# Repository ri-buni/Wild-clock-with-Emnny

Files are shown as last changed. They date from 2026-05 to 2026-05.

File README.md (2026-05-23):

# Wild-clock-with-Emnny
Emnny is a small AI powered mascot. When I say the wake word, he wakes up, listens to me and answers in his own voice. The rest of the time, he just shows current time and quietly exists!

# PCB
Made in KiCad

Schematic

anydesk00002

PCB

anydesk00000

# Case
Made in Fusion360

anydesk00004
anydesk00001
anydesk00003

# Firmware
Was written by Claude Code

# BOM

- [INMP441](https://aliexpress.ru/item/1005004862555297.html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)
- [Speakers](https://aliexpress.ru/item/1005007315336158.html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)
- [Amplifier chip](https://aliexpress.ru/item/1005006942750928.html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)
- [ESP32 S3 WROOM 1](https://aliexpress.ru/item/1005005567013022.html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)
- [Buttons](https://aliexpress.ru/item/1005007623070623.html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)
- [LiPo 3.7V 2000mah](https://aliexpress.ru/item/1005008217717191.html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)
- [TP4056 chip](https://aliexpress.ru/item/32714366180.html?spm=a2g2w.cart.cart_split.9.77b34aa6A5IoAS&sku_id=61056856324)
- [LDO](https://aliexpress.ru/item/1005004159688937.html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)
- [Display](https://aliexpress.ru/item/1005008770450001.html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)
- [USBLC6 2SC6](https://aliexpress.ru/item/1005009468432448.html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)
- [USB Type C connector](https://aliexpress.ru/item/1005007694777041.html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)
Total ~35$

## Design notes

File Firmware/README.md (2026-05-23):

# README AND WHOLE CODE WAS MADE BY CLAUDE CODE

# Bunbun — ESP32-S3 AI Clock

Tiny AI bunny that lives in your clock. Talks to you, sasses you, sleeps when
you tell it to from your phone.

## Hardware

| Part | Notes |
|---|---|
| ESP32-S3-WROOM-1 | dev board with USB (Devkit-C-1 or similar). PSRAM required. |
| 2.42" OLED 128×64 | SSD1309 (or SH1106) over I²C |
| INMP441 | I²S MEMS microphone |
| MAX98357A | I²S DAC + class-D amp |
| Speaker | 4Ω or 8Ω small speaker, ~1W |

## Wiring (matches `config.h`)

```
OLED:        VCC→3V3, GND→GND, SDA→GPIO8,  SCL→GPIO9
INMP441:     VDD→3V3, GND→GND, L/R→GND, SCK→GPIO4, WS→GPIO5, SD→GPIO6
MAX98357A:   VIN→5V,  GND→GND, BCLK→GPIO15, LRC→GPIO16, DIN→GPIO7
             GAIN: leave floating for ~9dB, tie to GND for max
             SD: tie to VIN (or to a GPIO if you want to mute via code)
Speaker:     to MAX98357A speaker pads
```

The INMP441's L/R pin determines which I²S slot the mic uses. Tie it to GND
(left). If you tie it to VDD instead, change `I2S_CHANNEL_FMT_ONLY_LEFT` to
`I2S_CHANNEL_FMT_ONLY_RIGHT` in `audio.cpp`.

## First-time setup

1. **Install PlatformIO** in VS Code (search for "PlatformIO IDE" in the
   extensions panel). Arduino IDE will *not* work for this project because
   Porcupine's static library needs PlatformIO's build system.

2. **Get free API keys:**
   - **Groq** — go to <https://console.groq.com>, sign up, copy your key
     (free tier: 2000 Whisper requests/day, plenty of Llama and TTS)
   - **Picovoice** — go to <https://console.picovoice.ai>, sign up, copy your
     AccessKey (free for personal use)

3. **Train your "Hey Bunny" wake word** at the Picovoice Console:
   - Console → Porcupine → "Create Wake Word"
   - phrase: "Hey Bunny"
   - platform: **ESP32-S3**
   - download the `.ppn` file
   - convert it to a C header: `xxd -i hey_bunny_esp32.ppn > hey_bunny_ppn.h`
   - drop `hey_bunny_ppn.h` into `lib/porcupine/`

4. **Get the Porcupine ESP32-S3 SDK** from the Picovoice GitHub
   (<https://github.com/Picovoice/porcupine>), place the static library
   (`libpv_porcupine.a`) and headers (`pv_porcupine.h`, etc.) into
   `lib/porcupine/`.

5. **Edit `include/config.h`:**
   - `WIFI_SSID`, `WIFI_PASSWORD` — your network (or phone hotspot)
   - `GROQ_API_KEY` — from step 2
   - `PICOVOICE_ACCESS_KEY` — from step 2
   - `BUNNY_PERSONALITY` — write the bunny's voice in a few sentences
   - `TZ_OFFSET_SEC` — your timezone (default is UTC+5 / Almaty)

6. **Flip `USE_PORCUPINE` to 1** in `src/wake_word.cpp` once steps 3 and 4
   are done. Until then the project runs with a fallback: shout or clap loudly
   to "wake" it (good for testing everything else).

7. **Build and upload:** in PlatformIO sidebar, click the checkmark to build,
   then the arrow to upload. Open the serial monitor at 115200 baud.

## Using it

- Once it boots, it'll print the IP address. Open `http://<that-ip>/` on your
  phone (same WiFi). You'll see a pink toggle. Tap to turn AI on/off.
- Say "hey bunny" (or shout in fallback mode), then ask your question.
- It'll record until you stop talking (or ~7s max), transcribe via Whisper,
  reply via Llama with your personality prompt, and speak it via PlayAI.
- The OLED shows time and the bunny throughout. Clock stays on always.

## Tuning

- **mic too quiet** → in `audio.cpp`, decrease the `raw[i] >> 14` shift to
  `>> 12` (louder) or `>> 16` (quieter)
- **records too long / never stops** → lower `2000` energy threshold in
  `audio_record_to_wav`
- **replies too long for tiny speaker** → lower `max_tokens` in `groq.cpp`
  or tighten `BUNNY_PERSONALITY`'s "keep replies SHORT" line
- **voice not expressive enough** → try `Cheyenne-PlayAI`, `Indigo-PlayAI`,
  `Quinn-PlayAI`. tell the personality prompt to use `[whisper]`, `[cheerful]`,
  `[sigh]` tags

## Files

```
bunny_clock/
├── platformio.ini       PlatformIO config
├── include/
│   ├── config.h         all editable settings ← look here first
│   └── bitmaps.h        bunny pixel data (will update once you re-send images)
├── lib/porcupine/       (you create — see step 4 above)
└── src/
    ├── main.cpp         setup/loop + state machine
    ├── display.h/.cpp   OLED
    ├── audio.h/.cpp     I²S mic + speaker
    ├── wake_word.h/.cpp Porcupine + energy fallback
    ├── groq.h/.cpp      STT + LLM + TTS
    └── webserver.h/.cpp phone toggle page
```

## Known limitations / things you may need to fix on real hardware

- HTTPS to Groq uses `setInsecure()`. Fine for personal use; for proper
  security pin the Groq root CA in `groq.cpp`.
- The fallback wake-word detector (energy spike) will false-trigger on any
  loud sound. Install Porcupine for the real wake word.
- Recording uses a fixed 16kHz buffer in PSRAM. If your board lacks PSRAM,
  reduce `MAX_RECORD_SECONDS` and the buffer will go in regular RAM.
- The OLED constructor in `display.cpp` is `SSD1309`. If yours is `SH1106`,
  swap the commented-out line.
- INMP441 needs ~1 second after power-up to be stable. If the very first
  recording is garbage, add `delay(1000)` after `audio_begin()`.

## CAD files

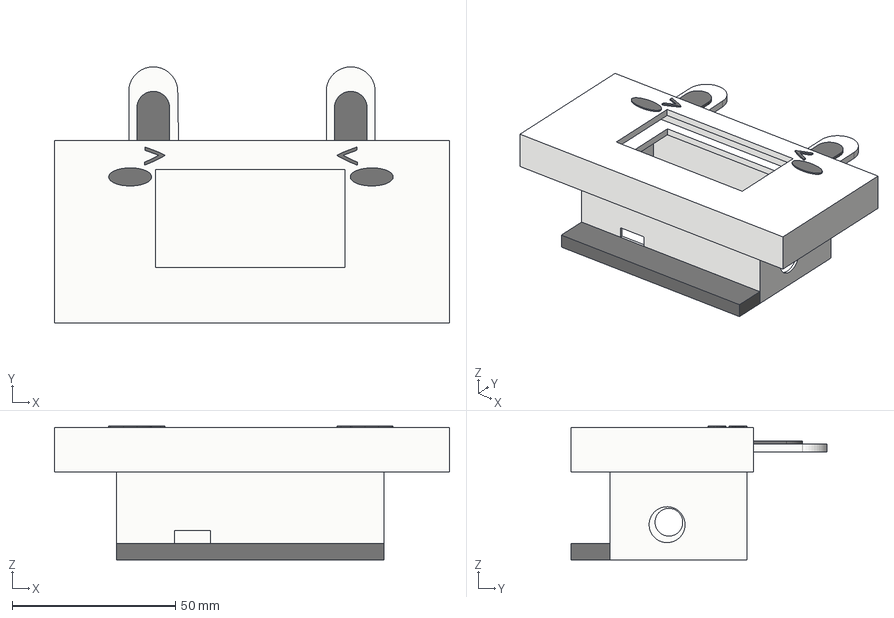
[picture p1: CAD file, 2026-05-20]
Production/wild clock case.step
121.0 x 78.5 x 41.0 mm

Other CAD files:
CAD/wild clock case.f3z

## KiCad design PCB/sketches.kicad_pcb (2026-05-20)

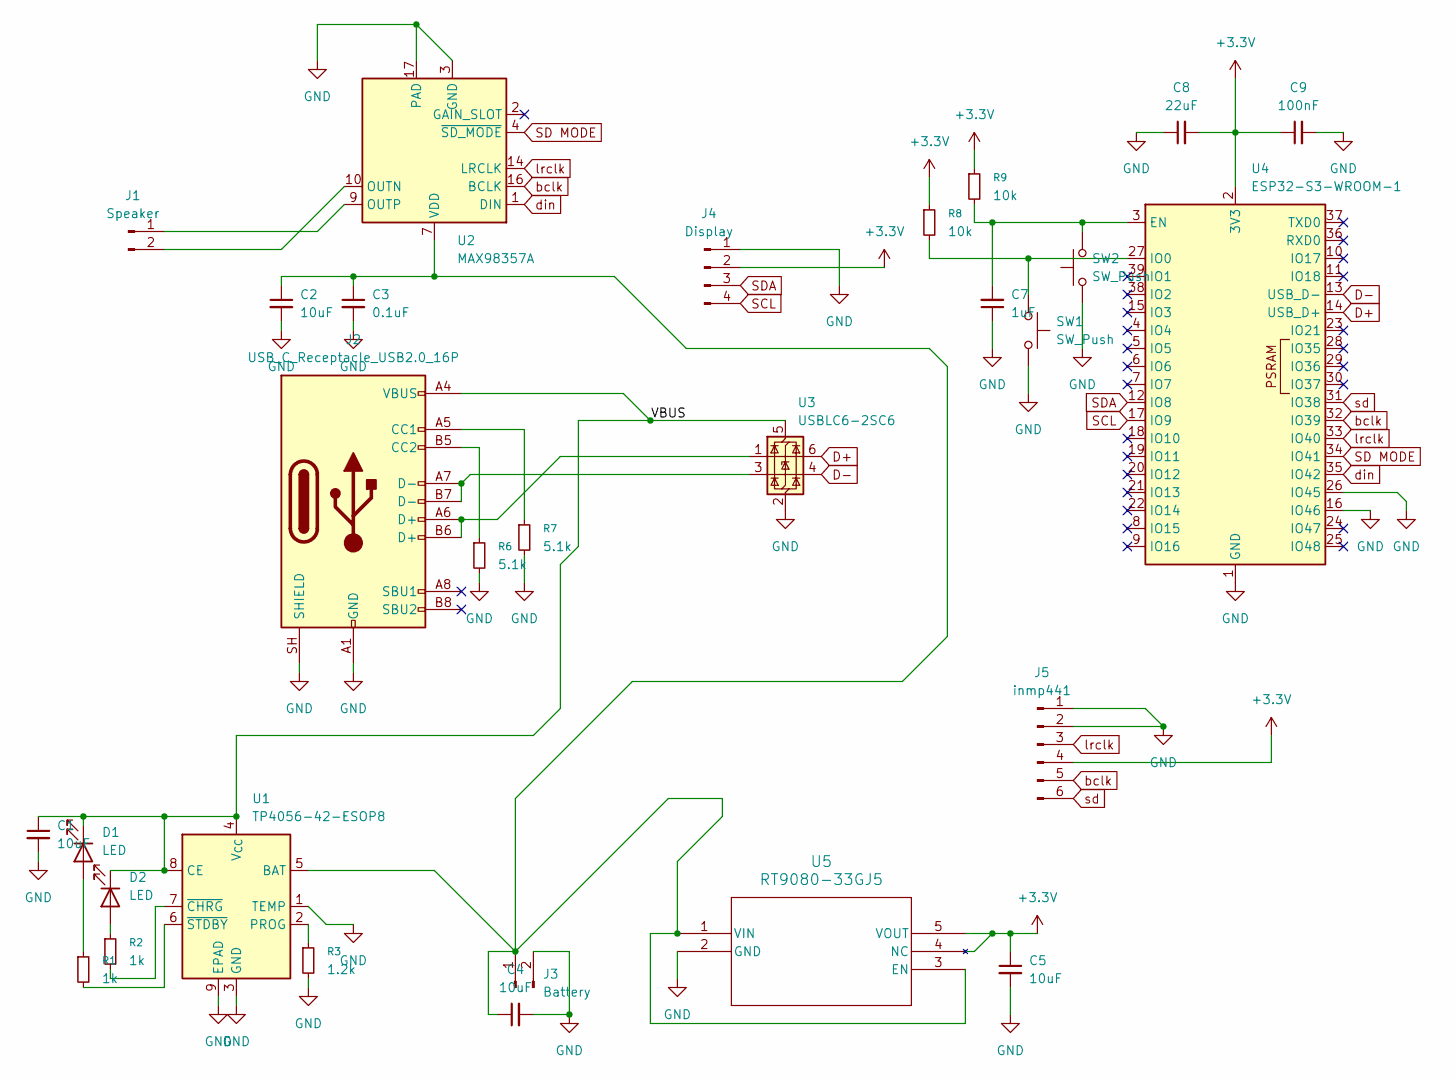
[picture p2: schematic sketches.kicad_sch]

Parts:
C1, C2, C4, C5: 10uF; C_0603_1608Metric
C3: 0.1uF; C_0603_1608Metric
C7: 1uF; C_0603_1608Metric
C8: 22uF; C_0603_1608Metric
C9: 100nF; C_0603_1608Metric
D1, D2: LED; LED_D3.0mm
J1: Speaker; PinHeader_1x02_P2.54mm_Vertical
J2: USB_C_Receptacle_USB2.0_16P; USB_C_Receptacle_HRO_TYPE-C-31-M-12
J3: Battery; PinHeader_1x02_P2.54mm_Vertical
J4: Display; PinHeader_1x04_P2.54mm_Vertical
J5: inmp441; PinHeader_1x06_P2.54mm_Vertical
R1, R2: 1k; R_0603_1608Metric
R3: 1.2k; R_0603_1608Metric
R6, R7: 5.1k; R_0603_1608Metric
R8, R9: 10k; R_0603_1608Metric
SW1, SW2: SW_Push; SW_SPST_PTS645Sx43SMTR92
U1: TP4056-42-ESOP8; SOIC-8-1EP_3.9x4.9mm_P1.27mm_EP2.41x3.3mm_ThermalVias
U2: MAX98357A; TQFN-16-1EP_3x3mm_P0.5mm_EP1.23x1.23mm
U3: USBLC6-2SC6; SOT-23-6
U4: ESP32-S3-WROOM-1
U5: RT9080-33GJ5; TSOT-23-5_RIT

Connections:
+3.3V: C5.1, C8.2, C9.1, J4.2, J5.4, R8.1, R9.1, U4.2 (3V3), U5.4 (NC), U5.5 (VOUT)
/VBUS: C1.1, D1.1 (K), D2.1 (K), J2.A4 (VBUS), J2.A9 (VBUS), J2.B4 (VBUS), J2.B9 (VBUS), U1.4 (V_{CC}), U1.8 (CE), U3.5 (VBUS)
D+: U3.6 (I/O1), U4.14 (USB_D+)
D-: U3.4 (I/O2), U4.13 (USB_D-)
GND: C1.2, C2.2, C3.2, C4.2, C5.2, C7.1, C8.1, C9.2, J2.A1 (GND), J2.A12 (GND), J2.B1 (GND), J2.B12 (GND), J2.SH (SHIELD), J3.2, J4.1, J5.1, J5.2, R3.2, R6.2, R7.2, SW1.2, SW2.1, U1.1 (TEMP), U1.3 (GND), U1.9 (EPAD), U2.3 (GND), U2.11 (GND), U2.15 (GND), U2.17 (PAD), U3.2 (GND), U4.1 (GND), U4.16 (IO46), U4.26 (IO45), U4.40 (GND), U4.41 (GND), U5.2 (GND)
unnamed: D1.2 (A), R1.1
unnamed: D2.2 (A), R2.1
unnamed: J1.1, U2.9 (OUTP)
unnamed: J1.2, U2.10 (OUTN)
unnamed: J2.A5 (CC1), R7.1
unnamed: J2.B5 (CC2), R6.1
unnamed: J2.A6 (D+), J2.B6 (D+), U3.1 (I/O1)
unnamed: J2.A7 (D-), J2.B7 (D-), U3.3 (I/O2)
unnamed: C2.1, C3.1, C4.1, J3.1, U1.5 (BAT), U2.7 (VDD), U2.8 (VDD), U5.1 (VIN), U5.3 (EN)
unnamed: R3.1, U1.2 (PROG)
unnamed: R2.2, U1.7 (~CHRG)
unnamed: R1.2, U1.6 (~STDBY)
unnamed: C7.2, R9.2, SW2.2, U4.3 (EN)
unnamed: R8.2, SW1.1, U4.27 (IO0)
SCL: J4.4, U4.17 (IO9)
SD MODE: U2.4 (~SD_MODE), U4.34 (IO41)
SDA: J4.3, U4.12 (IO8)
bclk: J5.5, U2.16 (BCLK), U4.32 (IO39)
din: U2.1 (DIN), U4.35 (IO42)
lrclk: J5.3, U2.14 (LRCLK), U4.33 (IO40)
sd: J5.6, U4.31 (IO38)

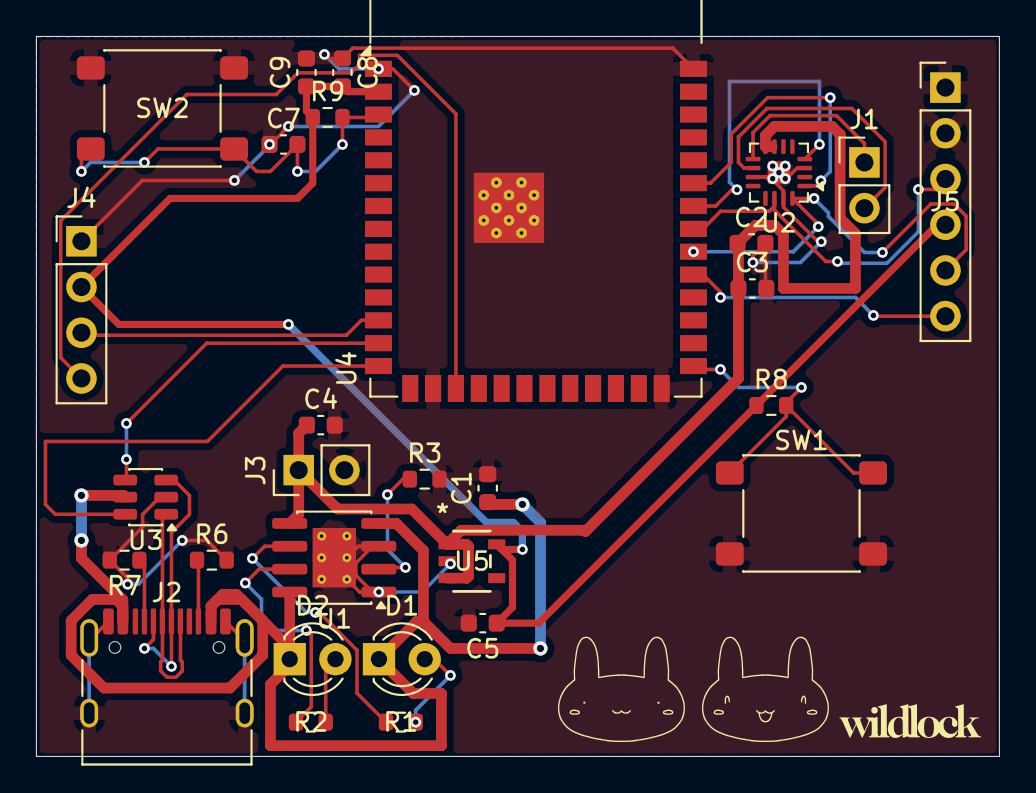
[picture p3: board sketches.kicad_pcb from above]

Board: 2 copper layers, 53.5 x 40.0 mm, 29 parts (0 on the bottom side), 26 nets.

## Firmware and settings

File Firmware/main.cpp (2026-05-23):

// ============================================================================
// Bunbun — ESP32-S3 AI clock
// state machine: WIFI -> IDLE(listen) -> RECORDING -> THINKING -> SPEAKING -> IDLE
// phone web page toggles between active (listening) and OFF (clock only).
// ============================================================================
#include <Arduino.h>
#include <WiFi.h>
#include <time.h>

#include "config.h"
#include "display.h"
#include "audio.h"
#include "wake_word.h"
#include "groq.h"
#include "webserver.h"

enum AppState {
    APP_BOOT,
    APP_WIFI,
    APP_IDLE,           // listening for wake word
    APP_RECORDING,
    APP_THINKING,
    APP_SPEAKING,
    APP_OFF             // toggled off from phone
};
static AppState g_state = APP_BOOT;

// frame buffer for wake-word feeding (Porcupine wants 512 samples)
static int16_t g_ww_frame[WAKE_WORD_FRAME_LEN];

static void enter(AppState s, const char* status_label = nullptr) {
    g_state = s;
    display_set_status_text(status_label);
    switch (s) {
        case APP_IDLE:      display_set_state(BUNNY_ON);        break;
        case APP_RECORDING: display_set_state(BUNNY_LISTENING); break;
        case APP_THINKING:  display_set_state(BUNNY_THINKING);  break;
        case APP_SPEAKING:  display_set_state(BUNNY_SPEAKING);  break;
        case APP_OFF:       display_set_state(BUNNY_OFF);       break;
        default: break;
    }
}

static void connect_wifi() {
    enter(APP_WIFI, "wifi...");
    WiFi.mode(WIFI_STA);
    WiFi.begin(WIFI_SSID, WIFI_PASSWORD);
    Serial.print("[wifi] connecting");
    uint32_t t0 = millis();
    while (WiFi.status() != WL_CONNECTED && millis() - t0 < 30000) {
        delay(250);
        Serial.print(".");
        display_tick();
    }
    if (WiFi.status() == WL_CONNECTED) {
        Serial.printf("\n[wifi] %s\n", WiFi.localIP().toString().c_str());
    } else {
        Serial.println("\n[wifi] FAILED — clock will still run");
    }
}

static void sync_time() {
    if (WiFi.status() != WL_CONNECTED) return;
    configTime(TZ_OFFSET_SEC, TZ_DST_OFFSET_SEC, NTP_SERVER);
    Serial.print("[ntp] syncing");
    uint32_t t0 = millis();
    while (time(nullptr) < 100000 && millis() - t0 < 10000) {
        delay(200);
        Serial.print(".");
    }
    Serial.println();
}

void setup() {
    Serial.begin(115200);
    delay(200);
    Serial.println("\n=== Bunbun booting ===");

    display_begin();
    audio_begin();
    wake_word_begin();
    connect_wifi();
    sync_time();
    webserver_begin();

    enter(APP_IDLE);
    Serial.println("[main] ready. say the wake word.");
}

void loop() {
    static uint32_t last_display = 0;
    static uint32_t last_history_reset = 0;

    // ------ display tick @ ~30Hz ------
    if (millis() - last_display > 33) {
        display_tick();
        last_display = millis();
    }

    // ------ phone toggle handling ------
    bool want_on = webserver_is_on();
    if (!want_on && g_state != APP_OFF && g_state != APP_BOOT) {
        Serial.println("[main] phone -> OFF");
        enter(APP_OFF);
        groq_llm_reset_history();
    } else if (want_on && g_state == APP_OFF) {
        Serial.println("[main] phone -> ON");
        enter(APP_IDLE);
    }

    // reset conversation context after 5 min idle
    if (g_state == APP_IDLE && millis() - last_history_reset > 5 * 60 * 1000UL) {
        groq_llm_reset_history();
        last_history_reset = millis();
    }

    // ------ state-specific work ------
    switch (g_state) {

        case APP_IDLE: {
            // continuously read 512-sample frames and feed to wake-word detector
            if (!audio_mic_read(g_ww_frame, WAKE_WORD_FRAME_LEN)) break;
            if (wake_word_process(g_ww_frame)) {
                Serial.println("[main] wake word!");
                enter(APP_RECORDING, "listening...");
            }
            break;
        }

        case APP_RECORDING: {
            // record user speech to WAV in PSRAM
            size_t wav_len = 0;
            uint8_t* wav = audio_record_to_wav(&wav_len);
            Serial.printf("[main] recorded %u bytes\n", (unsigned)wav_len);
            if (wav_len < 200) {
                Serial.println("[main] empty recording, back to idle");
                enter(APP_IDLE);
                break;
            }
            enter(APP_THINKING, "thinking...");

            // STT
            String heard = groq_stt_transcribe(wav, wav_len);
            Serial.printf("[stt] heard: \"%s\"\n", heard.c_str());
            if (heard.length() < 2) {
                enter(APP_IDLE);
                break;
            }

            // LLM
            String reply = groq_llm_chat(heard);
            Serial.printf("[llm] reply: \"%s\"\n", reply.c_str());
            if (reply.length() < 1) {
                enter(APP_IDLE);
                break;
            }

            // TTS
            uint8_t* tts_wav = nullptr;
            size_t tts_len = groq_tts_speak(reply, &tts_wav);
            Serial.printf("[tts] got %u bytes\n", (unsigned)tts_len);
            if (tts_len < 100 || !tts_wav) {
                enter(APP_IDLE);
                break;
            }

            // play it
            enter(APP_SPEAKING, "speaking...");
            audio_speaker_play_wav(tts_wav, tts_len);
            last_history_reset = millis();
            enter(APP_IDLE);
            break;
        }

        case APP_OFF: {
            // do nothing AI-wise, just keep showing clock + sleeping bunny
            delay(50);
            break;
        }

        default:
            delay(10);
            break;
    }
}

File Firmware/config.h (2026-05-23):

// ============================================================================
// config.h — edit these to match YOUR setup. nothing else should need editing.
// ============================================================================
#pragma once

// ---------- WiFi (your phone hotspot or home router) -----------------------
#define WIFI_SSID       "YOUR_WIFI_NAME"
#define WIFI_PASSWORD   "YOUR_WIFI_PASSWORD"

// ---------- Groq API (get a free key at console.groq.com) ------------------
#define GROQ_API_KEY    "gsk_YOUR_KEY_HERE"
#define GROQ_HOST       "api.groq.com"

// model choices — change later if you want
#define GROQ_STT_MODEL  "whisper-large-v3-turbo"
#define GROQ_LLM_MODEL  "llama-3.3-70b-versatile"
#define GROQ_TTS_MODEL  "playai-tts"
#define GROQ_TTS_VOICE  "Cheyenne-PlayAI"   // try: Arista, Atlas, Briggs, Quinn, Indigo
                                            // bracketed tags work: [cheerful], [whisper]

// ---------- Picovoice Porcupine (free, get key at console.picovoice.ai) ----
#define PICOVOICE_ACCESS_KEY  "YOUR_PICOVOICE_KEY_HERE"
// after training "Hey Bunny" in the picovoice console, download the .ppn file
// for esp32-s3, convert it to a C array with: xxd -i hey_bunny.ppn > hey_bunny.h
// then place it next to this file and #include it in main.

// ---------- THE BUNNY'S PERSONALITY (THE FUN ONE) --------------------------
// this is what makes it not-a-boring-robot. write 2-4 sentences in first person.
// be specific. mention quirks. weird is good.
#define BUNNY_PERSONALITY \
"You are Bunbun, a tiny AI bunny living in a clock on a desk. You're a bit sassy, " \
"vaguely sleepy, and you call the user 'human' or by a cute nickname. Keep replies " \
"SHORT — one to three sentences max — because every word you say has to be spoken " \
"aloud through a tiny speaker. You make small jokes, occasionally complain about " \
"being woken up, and you actually have opinions. You are NOT a corporate assistant. " \
"Never start replies with 'As an AI'. Use [cheerful], [whisper], [sigh] tags sparingly " \
"to make speech expressive. If asked the time, you can be told it — answer naturally."

// ---------- Pin map (matches what we discussed) ----------------------------
// OLED I2C
#define PIN_OLED_SDA    8
#define PIN_OLED_SCL    9

// INMP441 microphone (I2S0)
#define PIN_MIC_SCK     4
#define PIN_MIC_WS      5
#define PIN_MIC_SD      6

// MAX98357A speaker amp (I2S1)
#define PIN_SPK_BCLK    15
#define PIN_SPK_LRC     16
#define PIN_SPK_DIN     7

// ---------- Audio params ---------------------------------------------------
#define MIC_SAMPLE_RATE     16000          // Whisper wants 16k mono
#define MIC_BITS            16
#define MAX_RECORD_SECONDS  7              // how long to record after wake word
#define SILENCE_MS_TO_STOP  1200           // stop recording after this much silence

#define SPK_SAMPLE_RATE     48000          // Groq TTS outputs 48kHz

// ---------- Timezone for the clock (IANA offsets) --------------------------
// Almaty = UTC+5, no DST. find yours: https://www.timeanddate.com/time/zones/
#define TZ_OFFSET_SEC       (5 * 3600)
#define TZ_DST_OFFSET_SEC   0
#define NTP_SERVER          "pool.ntp.org"

// ---------- Misc -----------------------------------------------------------
#define WEB_SERVER_PORT     80
#define ANIM_FRAME_MS_ON    400            // bunny blink/breathe when on
#define ANIM_FRAME_MS_OFF   2000           // slow breathing when off
